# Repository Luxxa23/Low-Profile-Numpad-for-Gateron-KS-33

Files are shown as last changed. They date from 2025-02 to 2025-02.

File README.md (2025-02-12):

# Low Profile Numpad

for Gateron Low Profile 2.0 (KS-33) switches
Designed to fit in next to a Keychron K3 Max (or their other low profile keyboards)

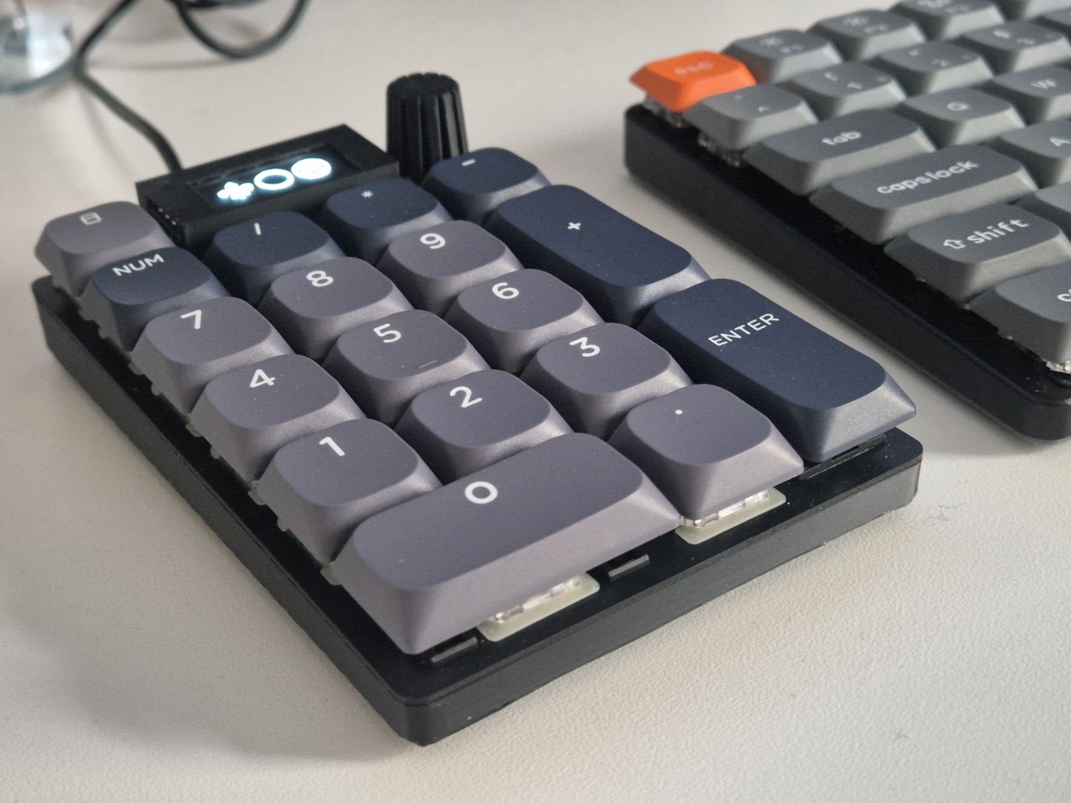
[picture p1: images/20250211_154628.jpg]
Low Profile Numpad for Gateron Low Profile 2.0 (KS-33) switches


## Design Process

The numpd was designed to match the outer dimensions of my Keychron K3 Max and use the same hotswap switches. The PCB was designed in [KiCad](https://github.com/KiCad), the case in Autodesk 
Fusion and the plate in [LibreCad](https://github.com/LibreCAD/LibreCAD) and imported into KiCad.
This was my first time designing a PCB, so the design is probably far from optimal. But it works!

Things to improve/do differently:
- Use the switches with a black housing to blend in with the black case
- Use original Keychron keycaps (if they sold them separately...)

## Building Materials

* Gateron [KS-33 Switches ](https://www.gateron.com/products/gateron-ks-33-low-profile-switch-set)
* Gateron [Low Profile Hotswap Sockets](https://www.gateron.com/products/gateron-low-profile-switch-hot-swap-pcb-socket)
* Gateron [Low Profile Stabilizers](https://www.gateron.com/products/gateron-low-profile-plate-mounted-stabilizer?VariantsId=10477)
* Wormier double-shot PBT keycaps [Aliexpress](https://aliexpress.com/item/1005008227731750.html)

* Adafruit [QT Py RP2040](https://www.adafruit.com/product/4900)
* 0.91" OLED Display (SSD1306) [Aliexpress](https://de.aliexpress.com/item/1005004622658983.html)
* Bourns PEC11R-4315F-S0012 [Encoder](https://www2.mouser.com/ProductDetail/652-PEC11R4315FS0012)
* PCBs ordered on [JLCPCB](https://jlcpcb.com/)
* M2 heat set inserts and screws

## Build Notes

* PCBs ordered on [JLCPCB](https://jlcpcb.com/). The main PCB is 1.6mm thick, the plate PCB is 1mm thick.

* The parts were printed on a BambuLab A1 using their black PLA Basic filament.

* The fit of the PCB is pretty tight, maybe it should've been a few millimetres wider. There are holes for M2x3 heat set inserts in the case. I used black M2x8 screws with a flat, non-countersunk head.
* I used a sharpie to paint the edge of the plate PCB black.
* Use thin, flexible wires for the encoder since there's no a lot of space in the case
*The cover for the OLED is only 0.6mm at the top, so it's very flimsy. If you have a smooth build plate print it upside down, I printed it using the top layer ironing feature with supports. The OLED is supposed to slide into the cover from the side. The fit is too tight, so use a small file to get it to fit perfectly.
*There are 11mm diameter, 1.5mm deep holes on the botton where for small rubber feet can be stuck.

## Firmware

Since the numpad is using an RP2040 processor, I decided to use [KMK Firmware](https://github.com/KMKfw/kmk_firmware).
I uploaded my code.py file, you'll have to install and set up KMK yourself (and edit the OLED display contents/make your own images for it)
My programming knowledge is pretty limited and there aren't a lot of resources on KMK online, so I didn't figure out how to get the display to show Num- and Caps lock without using dummy layers as variables.

## Inspiration and resources

Inspiration for plate PCB and distances between keys: https://github.com/shanna/pla_nck

KiCad footprint for Gateron Low Profile hotswap sockets: https://gist.github.com/niw/22c68c2d7c869b990588b4875a654442 

## Gallery

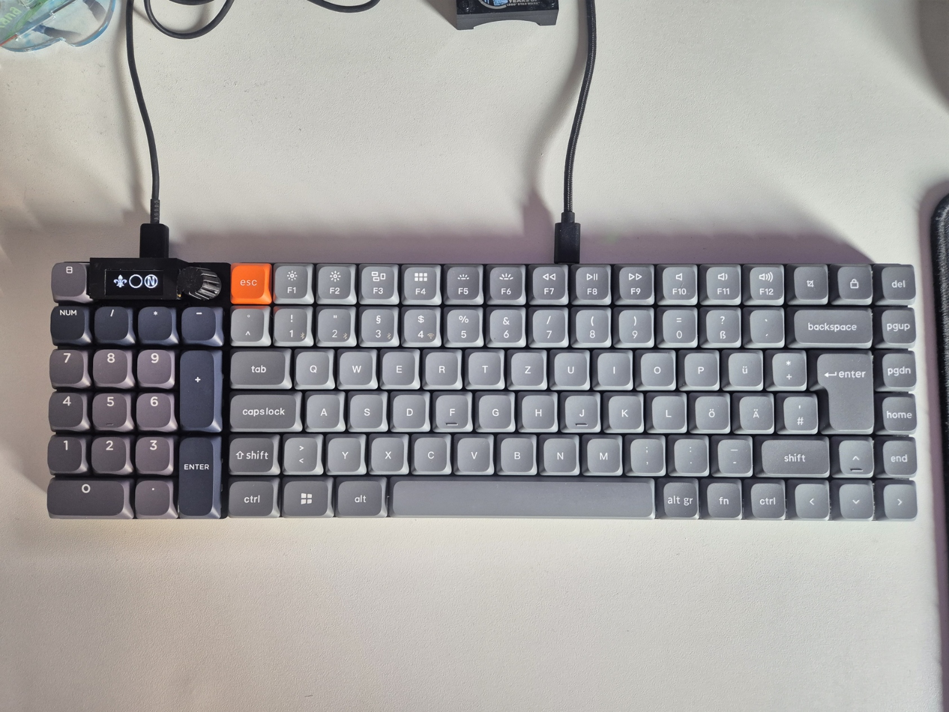
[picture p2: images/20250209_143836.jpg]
Numpad with Keychron K3 Max

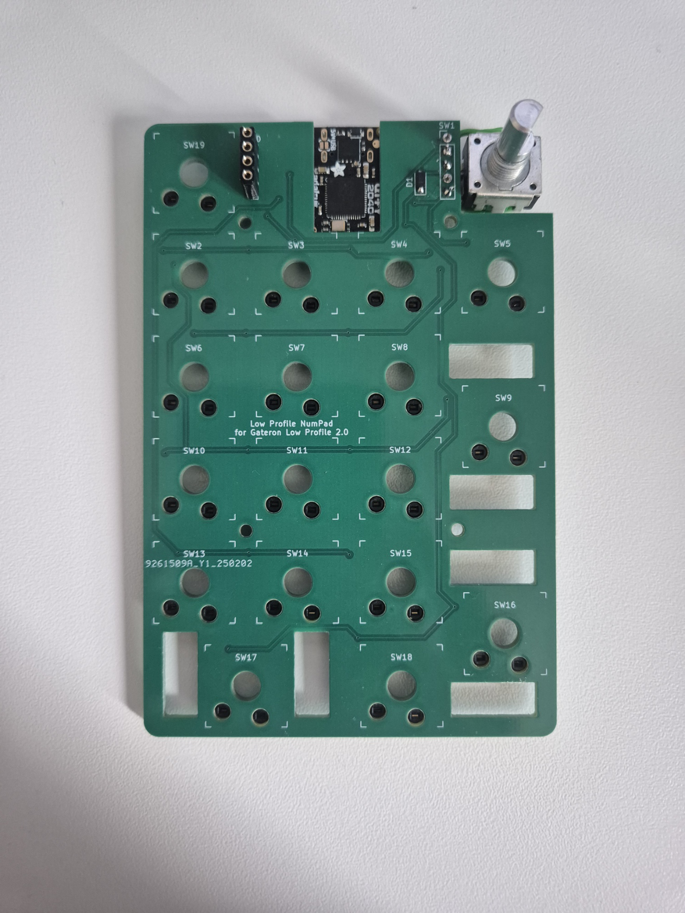
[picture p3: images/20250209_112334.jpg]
PCB Front

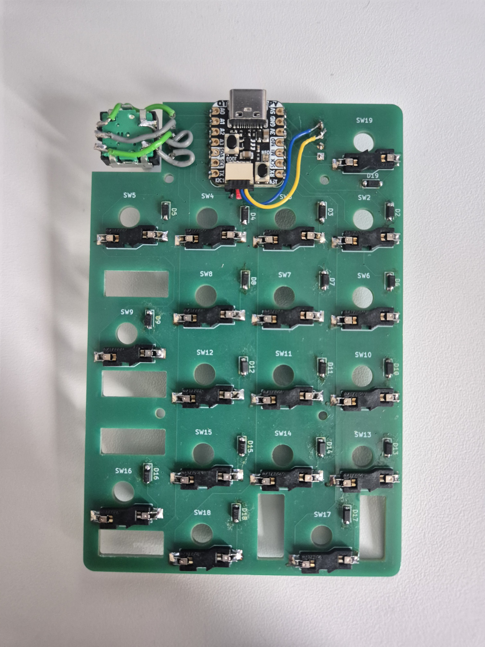
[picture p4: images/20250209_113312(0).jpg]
PCB Back

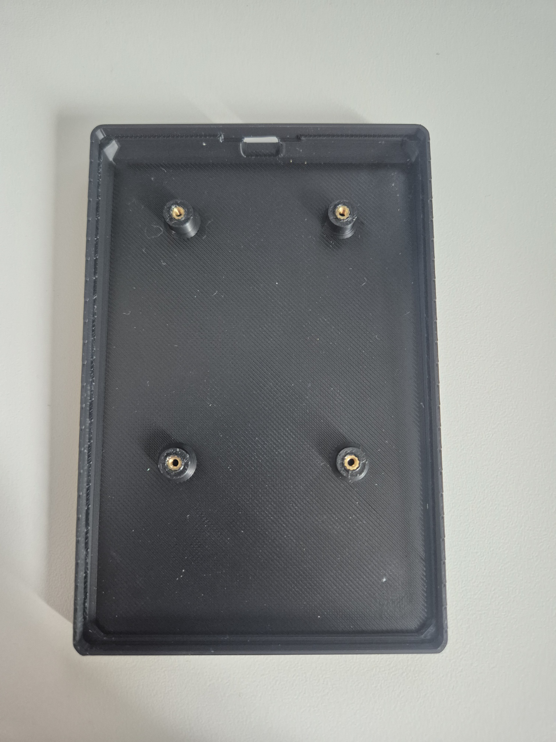
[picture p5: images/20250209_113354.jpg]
Case

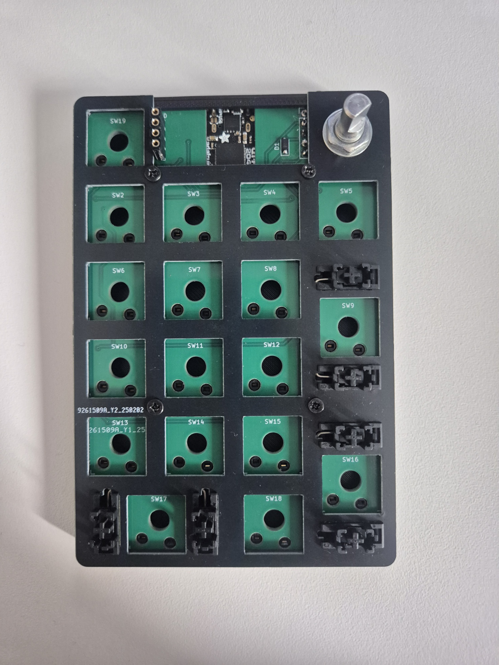
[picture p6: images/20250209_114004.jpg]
Numpd without switches


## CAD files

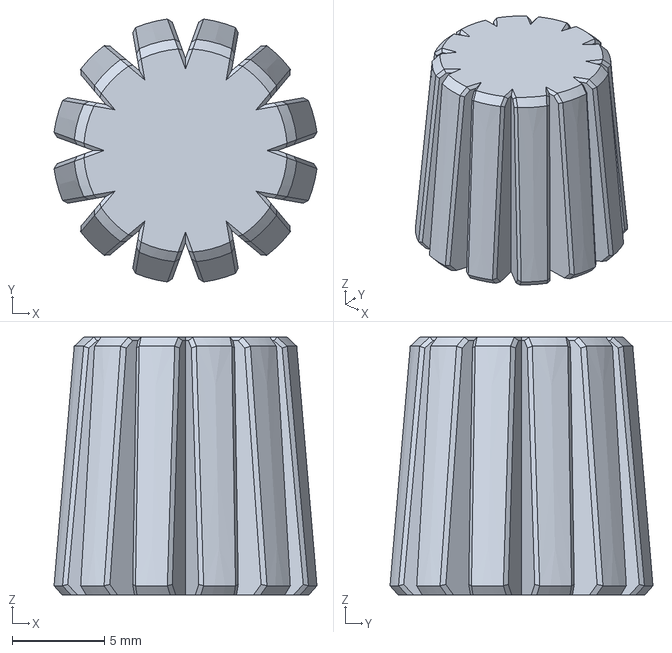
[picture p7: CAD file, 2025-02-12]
case/Low Profile Numpad encoder knob.step
14.3 x 14.3 x 14.0 mm

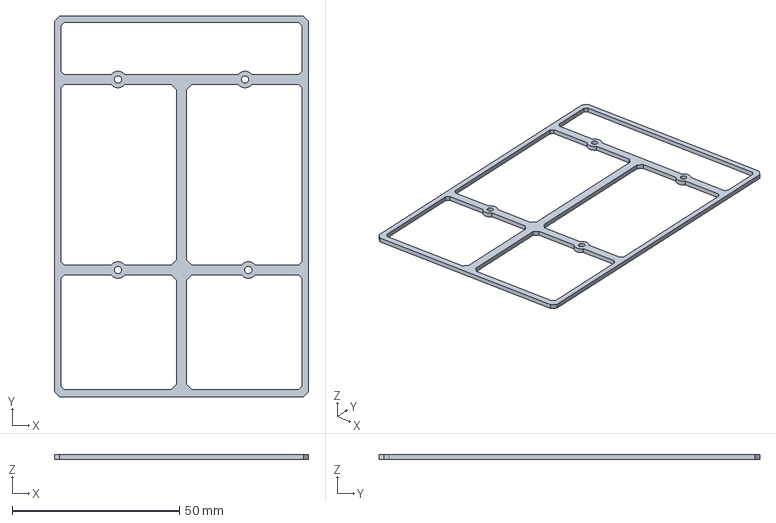
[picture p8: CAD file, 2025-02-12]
case/Low Profile Numpad spacer.step
76.0 x 114.0 x 1.50 mm

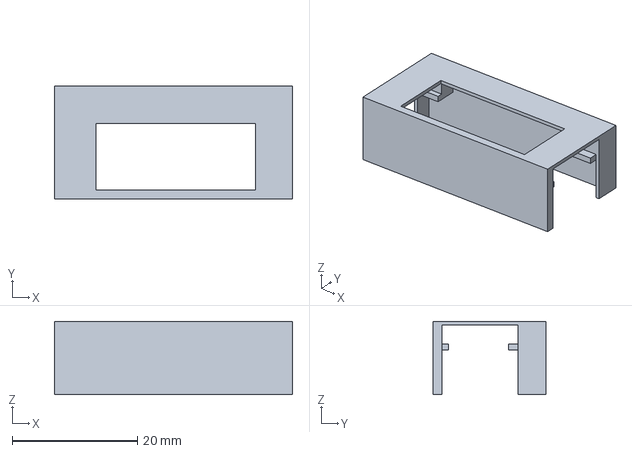
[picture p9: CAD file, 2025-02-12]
case/Low Profile Numpad OLED cover.step
38.0 x 18.0 x 11.7 mm

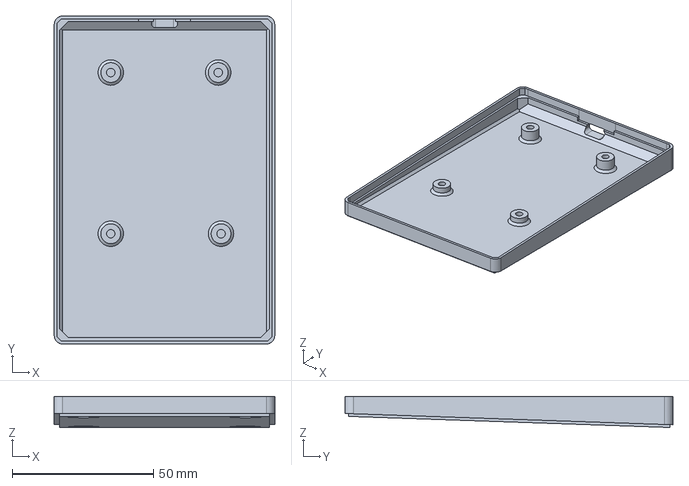
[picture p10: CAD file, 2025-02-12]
case/Low Profile Numpad Case.step
78.0 x 116.0 x 11.0 mm

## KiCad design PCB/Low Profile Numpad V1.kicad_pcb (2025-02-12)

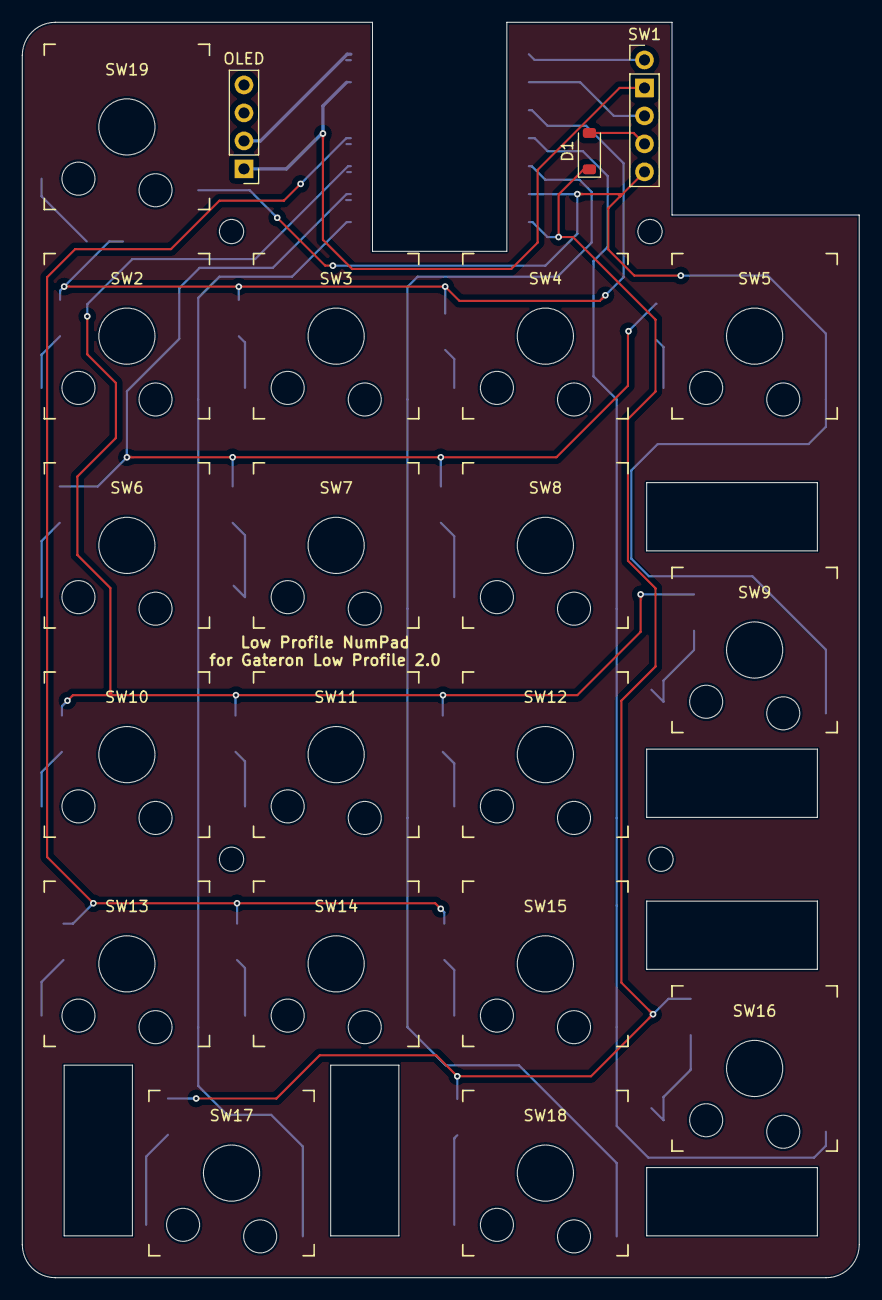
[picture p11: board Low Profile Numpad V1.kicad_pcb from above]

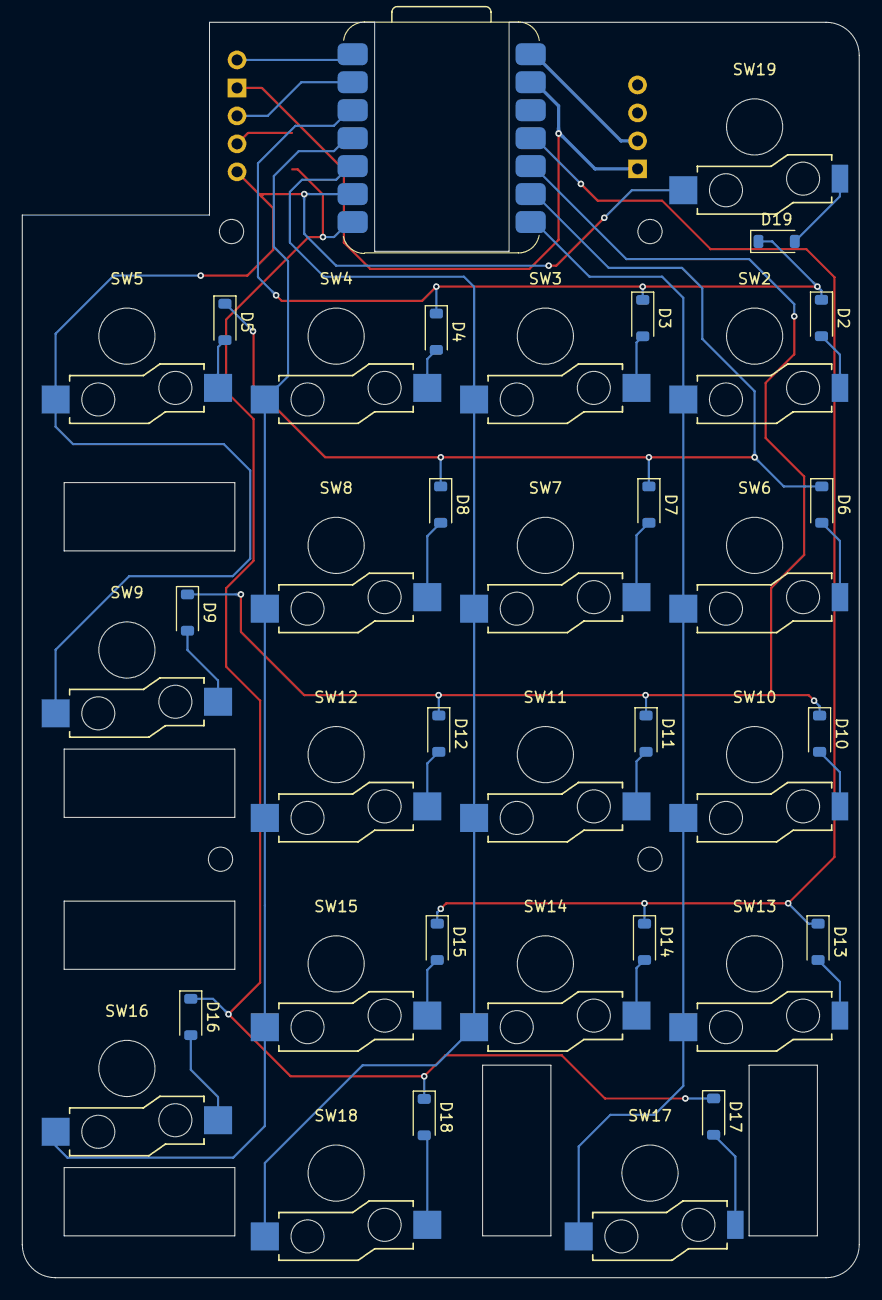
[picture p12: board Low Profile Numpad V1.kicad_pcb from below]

Board: 2 copper layers, 76.0 x 114.0 mm, 40 parts (19 on the bottom side), 31 nets.

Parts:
D1, D2, D3, D4, D5, D6, D7, D8, D9, D10, D11, D12, D13, D14, D15, D16, D17, D18, D19: 1N4148W; D_SOD-123
OLED: PinHeader_1x04_P2.54mm_Vertical
SW1: RotaryEncoder_Switch; PinHeader_1x05_P2.54mm_Vertical
SW2, SW6, SW10, SW13, SW19: SW_DPST_x2; Gateron_Low_Profile_Socket (small left pad)
SW3, SW4, SW5, SW7, SW8, SW9, SW11, SW12, SW14, SW15, SW16, SW17, SW18: SW_DPST_x2; Gateron_Low_Profile_Socket
U2: XIAO-RP2040-DIP; Adafrui QT Py RP2040 SMD

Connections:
Column 0: SW2.2 (B), SW6.2 (B), SW10.2 (B), SW13.2 (B), SW17.2 (B), U2.8 (GPIO1/RX)
Column 1: SW3.2 (B), SW7.2 (B), SW11.2 (B), SW14.2 (B), SW18.2 (B), U2.5 (GPIO6/SDA)
Column 2: SW4.2 (B), SW8.2 (B), SW12.2 (B), SW15.2 (B), SW16.2 (B), U2.4 (GPIO29/ADC3/A3)
Column 3: SW1.5, SW5.2 (B), SW9.2 (B), SW19.2 (B), U2.6 (GPIO7/SCL)
GND: OLED.1, SW1.2, U2.13 (GND)
unnamed: D1.2 (A), SW1.4
unnamed: D2.2 (A), SW2.1 (A)
unnamed: D3.2 (A), SW3.1 (A)
unnamed: D4.2 (A), SW4.1 (A)
unnamed: D5.2 (A), SW5.1 (A)
unnamed: D6.2 (A), SW6.1 (A)
unnamed: D7.2 (A), SW7.1 (A)
unnamed: D8.2 (A), SW8.1 (A)
unnamed: D9.2 (A), SW9.1 (A)
unnamed: D10.2 (A), SW10.1 (A)
unnamed: D11.2 (A), SW11.1 (A)
unnamed: D12.2 (A), SW12.1 (A)
unnamed: D13.2 (A), SW13.1 (A)
unnamed: D14.2 (A), SW14.1 (A)
unnamed: D15.2 (A), SW15.1 (A)
unnamed: D16.2 (A), SW16.1 (A)
unnamed: D17.2 (A), SW17.1 (A)
unnamed: D18.2 (A), SW18.1 (A)
unnamed: D19.2 (A), SW19.1 (A)
unnamed: SW1.1, U2.1 (GPIO26/ADC0/A0)
unnamed: SW1.3, U2.2 (GPIO27/ADC1/A1)
Row 0: D2.1 (K), D3.1 (K), D4.1 (K), D19.1 (K), U2.3 (GPIO28/ADC2/A2)
Row 1: D5.1 (K), D6.1 (K), D7.1 (K), D8.1 (K), U2.9 (GPIO2/SCK)
Row 2: D9.1 (K), D10.1 (K), D11.1 (K), D12.1 (K), U2.10 (GPIO4/MISO)
Row 3: D13.1 (K), D14.1 (K), D15.1 (K), U2.11 (GPIO3/MOSI)
Row 4: D1.1 (K), D16.1 (K), D17.1 (K), D18.1 (K), U2.7 (GPIO0/TX)

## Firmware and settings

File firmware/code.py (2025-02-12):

print("Starting")

import board
import busio

from kmk.kmk_keyboard import KMKKeyboard
from kmk.keys import KC
from kmk.scanners import DiodeOrientation
from kmk.modules.layers import Layers
from kmk.modules.encoder import EncoderHandler
from kmk.extensions.media_keys import MediaKeys
from kmk.extensions.display import Display, SSD1306, TextEntry, ImageEntry
from kmk.extensions.display.ssd1306 import SSD1306
from kmk.extensions.lock_status import LockStatus
from kmk.modules.holdtap import HoldTap
from kmk.modules.macros import Macros, Press, Release, Tap, Delay


keyboard = KMKKeyboard()
layers = Layers()
holdtap = HoldTap()
encoder_handler = EncoderHandler()
macros = Macros()

keyboard.modules = [encoder_handler, holdtap, macros]
keyboard.extensions.append(MediaKeys())


keyboard.col_pins = (board.RX, board.SDA, board.A3, board.SCL)
keyboard.row_pins = (board.A2, board.SCK, board.MISO, board.MOSI, board.TX)
keyboard.diode_orientation = DiodeOrientation.COL2ROW


#GPIO Encoder
encoder_handler.pins = (board.A1, board.A0, None,),
encoder_handler.divisor = 4


i2c_bus = busio.I2C(board.SCL1, board.SDA1)

display_driver = SSD1306(
    i2c=i2c_bus,
#    device_address=0x3C,
)


#Layout to matrix:
#        Col0   Col1   Col2      Col3
#Row0    NUM     /       *       Top left (SW19)
#Row1    7       8       9       -
#Row2    4       5       6       +
#Row3    1       2       3
#Row4    0       ,       Enter   EncoderSW


CALC = KC.MACRO(
    Press(KC.LGUI),
    Tap(KC.R),
    Release(KC.LGUI),
    Delay(250),
    "calc.exe",
    Tap(KC.ENTER),
)
LAYER_TAP = KC.HT(CALC, KC.MO(4), prefer_hold=True, tap_interrupted=False, tap_time=250)


keyboard.keymap = [
    #base layer 0
    [
         KC.NUMLOCK, KC.KP_SLASH, KC.KP_ASTERISK, LAYER_TAP,
         KC.KP_7, KC.KP_8, KC.KP_9, KC.KP_MINUS,
         KC.KP_4, KC.KP_5, KC.KP_6, KC.KP_PLUS,
         KC.KP_1, KC.KP_2, KC.KP_3, KC.B,
         KC.KP_0, KC.KP_DOT, KC.KP_ENTER, KC.MEDIA_PLAY_PAUSE,
    ],
    #caps layer 1
    [
         KC.NUMLOCK, KC.KP_SLASH, KC.KP_ASTERISK, LAYER_TAP,
         KC.KP_7, KC.KP_8, KC.KP_9, KC.KP_MINUS,
         KC.KP_4, KC.KP_5, KC.KP_6, KC.KP_PLUS,
         KC.KP_1, KC.KP_2, KC.KP_3, KC.B,
         KC.KP_0, KC.KP_DOT, KC.KP_ENTER, KC.MEDIA_PLAY_PAUSE,
    ],
    #num layer 2
    [
         KC.NUMLOCK, KC.KP_SLASH, KC.KP_ASTERISK, LAYER_TAP,
         KC.KP_7, KC.KP_8, KC.KP_9, KC.KP_MINUS,
         KC.KP_4, KC.KP_5, KC.KP_6, KC.KP_PLUS,
         KC.KP_1, KC.KP_2, KC.KP_3, KC.B,
         KC.KP_0, KC.KP_DOT, KC.KP_ENTER, KC.MEDIA_PLAY_PAUSE,
    ],
    #num+caps layer 3
    [
         KC.NUMLOCK, KC.KP_SLASH, KC.KP_ASTERISK, LAYER_TAP,
         KC.KP_7, KC.KP_8, KC.KP_9, KC.KP_MINUS,
         KC.KP_4, KC.KP_5, KC.KP_6, KC.KP_PLUS,
         KC.KP_1, KC.KP_2, KC.KP_3, KC.B,
         KC.KP_0, KC.KP_DOT, KC.KP_ENTER, KC.MEDIA_PLAY_PAUSE,
    ],
    # vol knob layer 4
    [
         KC.NUMLOCK, KC.KP_SLASH, KC.KP_ASTERISK, KC.TRNS,
         KC.KP_7, KC.KP_8, KC.KP_9, KC.KP_MINUS,
         KC.KP_4, KC.KP_5, KC.KP_6, KC.KP_PLUS,
         KC.KP_1, KC.KP_2, KC.KP_3, KC.B,
         KC.KP_0, KC.KP_DOT, KC.KP_ENTER, KC.MUTE,
    ],
]


encoder_handler.map = [ ((KC.MEDIA_PREV_TRACK, KC.MEDIA_NEXT_TRACK),), #layer 0
                        ((KC.MEDIA_PREV_TRACK, KC.MEDIA_NEXT_TRACK),), #layer 1
                        ((KC.MEDIA_PREV_TRACK, KC.MEDIA_NEXT_TRACK),), #layer 2
                        ((KC.MEDIA_PREV_TRACK, KC.MEDIA_NEXT_TRACK),), #layer 3
                        ((KC.AUDIO_VOL_DOWN, KC.AUDIO_VOL_UP),), #layer 4
                      ]


display = Display(
    display=display_driver,
    height=32,
    dim_time=10,
    dim_target=0.1,
    off_time=1800,
    brightness=1,
)


class OLEDLockStatus(LockStatus):

    def set_lock_oled(self):
        if self.get_caps_lock() and self.get_num_lock() == False:
            keyboard.tap_key(KC.DF(1))
        elif self.get_num_lock() and self.get_caps_lock() == False:
            keyboard.tap_key(KC.DF(2))
        elif self.get_num_lock() and self.get_caps_lock():
            keyboard.tap_key(KC.DF(3))
        elif self.get_num_lock() == False and self.get_caps_lock() == False:
            keyboard.tap_key(KC.DF(0))

    def after_hid_send(self, sandbox):
        super().after_hid_send(sandbox)  # Critically important. Do not forget
        if self.report_updated:
            self.set_lock_oled()


display.entries = [
    ImageEntry(image="None.bmp", x=0, y=0, layer=0),
    ImageEntry(image="C.bmp", x=0, y=0, layer=1),
    ImageEntry(image="N.bmp", x=0, y=0, layer=2),
    ImageEntry(image="CN.bmp", x=0, y=0, layer=3),
    ImageEntry(image="Vol.bmp", x=0, y= 0, layer= 4),
]


keyboard.extensions.append(display)
keyboard.extensions.append(OLEDLockStatus())
keyboard.extensions.append(Layers)

if __name__ == '__main__':
    keyboard.go()
